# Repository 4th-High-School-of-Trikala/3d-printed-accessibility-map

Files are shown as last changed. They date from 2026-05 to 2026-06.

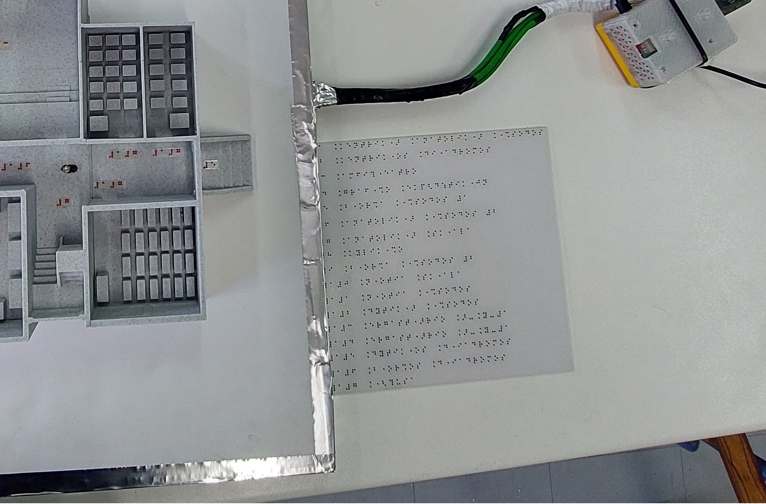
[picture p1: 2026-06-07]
3dSchoolFloorPlan/photos/floor-plan-21.jpg

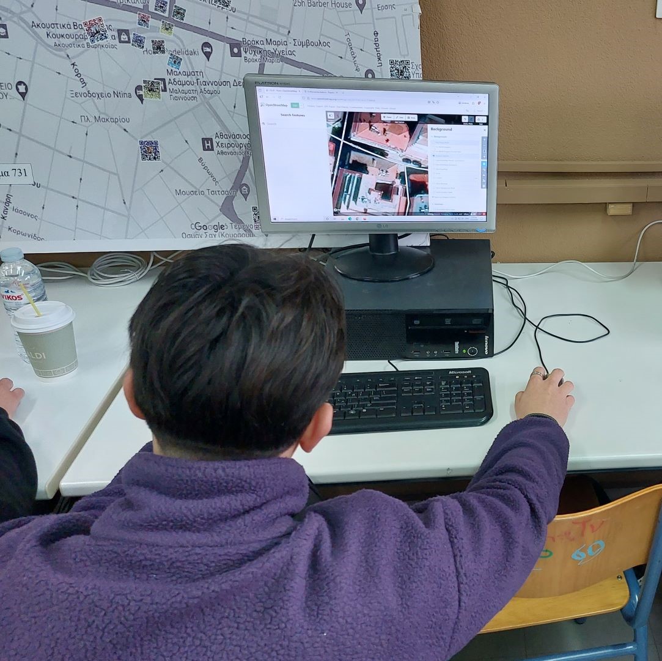
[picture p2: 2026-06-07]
3DMapTrikala/photos/map-3.jpg

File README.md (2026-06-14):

# Διαδραστικός 3D Εκτυπωμένος Χάρτης Προσβασιμότητας
Οι μαθητές, οι μαθήτριες και οι εκπαιδευτικοί των Ομίλων «STEM, 3D & AI» και «TechArt: Τεχνολογία, Δημιουργία, Καινοτομία» του 4ου Πειραματικού ΓΕΛ Τρικάλων, κατασκεύασαν ένα καινοτόμο εκπαιδευτικό έργο **σε πραγματική κλίμακα**, που αξιοποιεί την τεχνολογία, για την ενίσχυση της προσβασιμότητας στην πολιτιστική κληρονομιά της πόλης των Τρικάλων.  
Πιο συγκεκριμένα, σχεδιάσαν και εκτύπωσαν με τεχνολογία FDM 3D εκτύπωσης δύο ανάγλυφους χάρτες (χάρτες αφής):
- Ο πρώτος χάρτης αφορά την πόλη των Τρικάλων και αναπαριστά δρόμους, ποτάμια, κτήρια και πεζοδρόμια, με σκοπό να διευκολυνθεί η πλοήγηση ατόμων με προβλήματα όρασης στα κυριότερα ιστορικά σημεία και αξιοθέατα. Σε κάθε σημείο ενδιαφέροντος (μνημεία, αγάλματα, αξιοθέατα) της πόλης, τοποθετήθηκαν διαδραστικά κουμπιά, (push buttons ή αφής), τα οποία συνδέθηκαν με μικροϋπολογιστή Raspberry Pi και προγραμματίστηκαν κατάλληλα ώστε με το πάτημα κάθε κουμπιού να προβάλλεται σε οθόνη, βίντεο με ιστορικές πληροφορίες (και κατάλληλο QR Code) και να **ακούγεται** η αντίστοιχη περιγραφή του σημείου. Τα βίντεο έχουν ήδη δημιουργηθεί από συμμαθητές/τριες τους, στο πλαίσιο πολιτιστικού προγράμματος.
- Ο δεύτερος χάρτης (τρισδιάστατη κάτοψη) αφορά το σχολείο μας (και τους 2 ορόφους) και δημιουργήθηκε ως παράδειγμα υλοποίησης 3D αναπαράστασης ενός σημείου ενδιαφέροντος. Η δεύτερη αναπαράσταση βοηθά στην περιήγηση στο σημείο ενδιαφέροντος και μπορεί να δημιουργηθεί για κάθε ένα από τα μνημεία/αξιοθέατα/αγάλματα κτλ.

Με τον τρόπο αυτό όλοι οι επισκέπτες και οι κάτοικοι της πόλης μας αποκτούν ισότιμη πρόσβαση στην πολιτιστική της κληρονομιά.

## Ενδεικτική λίστα υλικών

- Ένα (ή δύο ανάλογα με την υλοποίηση) Raspberry Pi (με κάρτα μνήμης τουλάχιστον 16 GB) και παρελκόμενα
- 8 Stomp Switches (non-latching) ή push buttons.
- 5 αισθητήρες απόστασης/αποφυγής εμποδίων (υπερύθρων - TCRT5000)
- 16 αντιστάσεις, 8 πυκνωτές, μία διάτρητη πλακέτα και 10 κλέμες
- Καλωδίωση, μη ευαίσθητη στις παρεμβολές, κατάλληλη για την σύνδεση των κουμπιών με το Raspberry Pi.
- Κατάλληλο πλαίσιο και βάση (μακετόχαρτο) για την στήριξη των χαρτών (100x70 εκατοστά)
- Filament για την εκτύπωση του χάρτη και των κατόψεων (περίπου 3 κιλά).
- C-Media USB Headphone Set (USB κάρτα ήχου)

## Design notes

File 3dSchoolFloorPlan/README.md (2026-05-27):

Το πρόγραμμα πίσω απο το «Διαδραστικό 3D Εκτυπωμένο Σημείο Ενδιαφέροντος», των Ομίλων «STEM, 3D & AI» και «TechArt: Τεχνολογία, Δημιουργία, Καινοτομία» του 4ου Πειραματικού ΓΕΛ Τρικάλων. Γραμμένο σε Python, απο τους μαθητές του Ομίλου, για να τρέχει στα Raspberry Pi.

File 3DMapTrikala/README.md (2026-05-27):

# 4peirlyk PyVLC Player
Το πρόγραμμα πίσω απο τον «Διαδραστικό 3D Εκτυπωμένο Χάρτη Προσβασιμότητας», των Ομίλων «STEM, 3D & AI» και «TechArt: Τεχνολογία, Δημιουργία, Καινοτομία» του 4ου Πειραματικού ΓΕΛ Τρικάλων.
Γραμμένο σε Python, απο τους μαθητές του Ομίλου, για να τρέχει στα Raspberry Pi.

## Οργάνωση του Project

```bash
.
├── config.toml: Ρυθμίσεις Προγράμματος
└── src
    ├── gpio.py: Διαχείριση GPIO 
    ├── gui 
    │   ├── alert.py: Παράθυρο Ειδοποίησης
    │   └── vlc.py: VLC Player
    ├── main.py: Σημείο εισόδου
    ├── qr.py: Δημιουργία QR Code
    └── uri.py: Έλεγχος URI 
```

## Demo

```mermaid
sequenceDiagram
  participant Οθόνη
  participant Πρόγραμμα
  participant RPI
  actor Χρήστης

  Note over RPI: Η δοκιμασμένη πλατφόρμα ήταν ένα Raspberry Pi 4.<br/>Λογικά λειτουργεί με όλες τις κύριες πλακέτες RPI.
  Note over Πρόγραμμα,RPI: Διαδικασία εκκίνησης
  Πρόγραμμα ->> Πρόγραμμα: Προφόρτωση μέσων και έλεγχος εγκυρότητας URI

  Πρόγραμμα ->> RPI: Ρύθμιση GPIO
  Πρόγραμμα ->> Πρόγραμμα: Εγγραφή αναπαραγώγιμων πολυμέσεων και Callback

  Πρόγραμμα ->> Οθόνη: Εγγραφή πολυμέσων και εγγραφή Callback
  Πρόγραμμα ->> Οθόνη: Αναπαραγωγή IDLE

  Note over Πρόγραμμα,RPI: Διαδικασία μετά το πάτημα του κουμπιού
  Χρήστης ->> RPI: Πάτημα κουμπιού
  RPI -->> Πρόγραμμα: Κλήση Callback
  Πρόγραμμα ->> Πρόγραμμα: Φορτώνει το κατάλληλο πολυμέσο από Ρυθμίσεις
  Πρόγραμμα ->> Πρόγραμμα: Δημιουργία QR κωδικού
  Πρόγραμμα ->> Οθόνη: Ορισμός πολυμέσων από λίστα
  Πρόγραμμα ->> Οθόνη: Επικάλυψη QR Code

  Note over Πρόγραμμα,RPI: Όταν ολοκληρωθεί η <br/> αναπαραγωγή πολυμέσων
  Πρόγραμμα ->> Οθόνη: Αναπαραγωγή IDLE
  Πρόγραμμα ->> Οθόνη: Απόκρυψη κωδικού QR
```

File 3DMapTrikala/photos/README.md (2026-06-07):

Φωτογραφίες από την διαδικασία σχεδίασης και κατασκευής

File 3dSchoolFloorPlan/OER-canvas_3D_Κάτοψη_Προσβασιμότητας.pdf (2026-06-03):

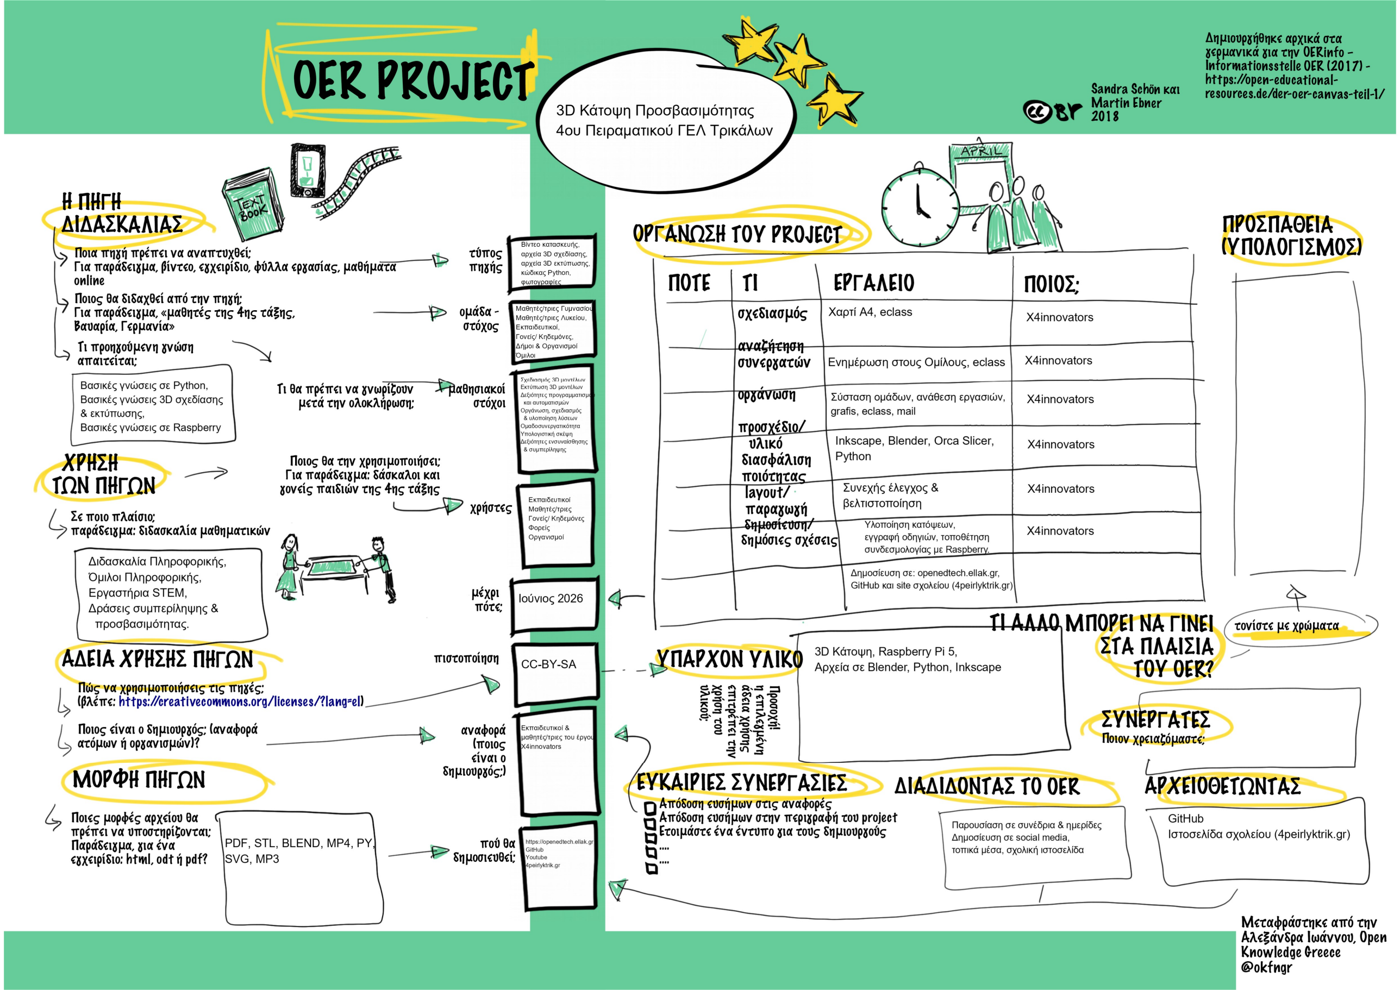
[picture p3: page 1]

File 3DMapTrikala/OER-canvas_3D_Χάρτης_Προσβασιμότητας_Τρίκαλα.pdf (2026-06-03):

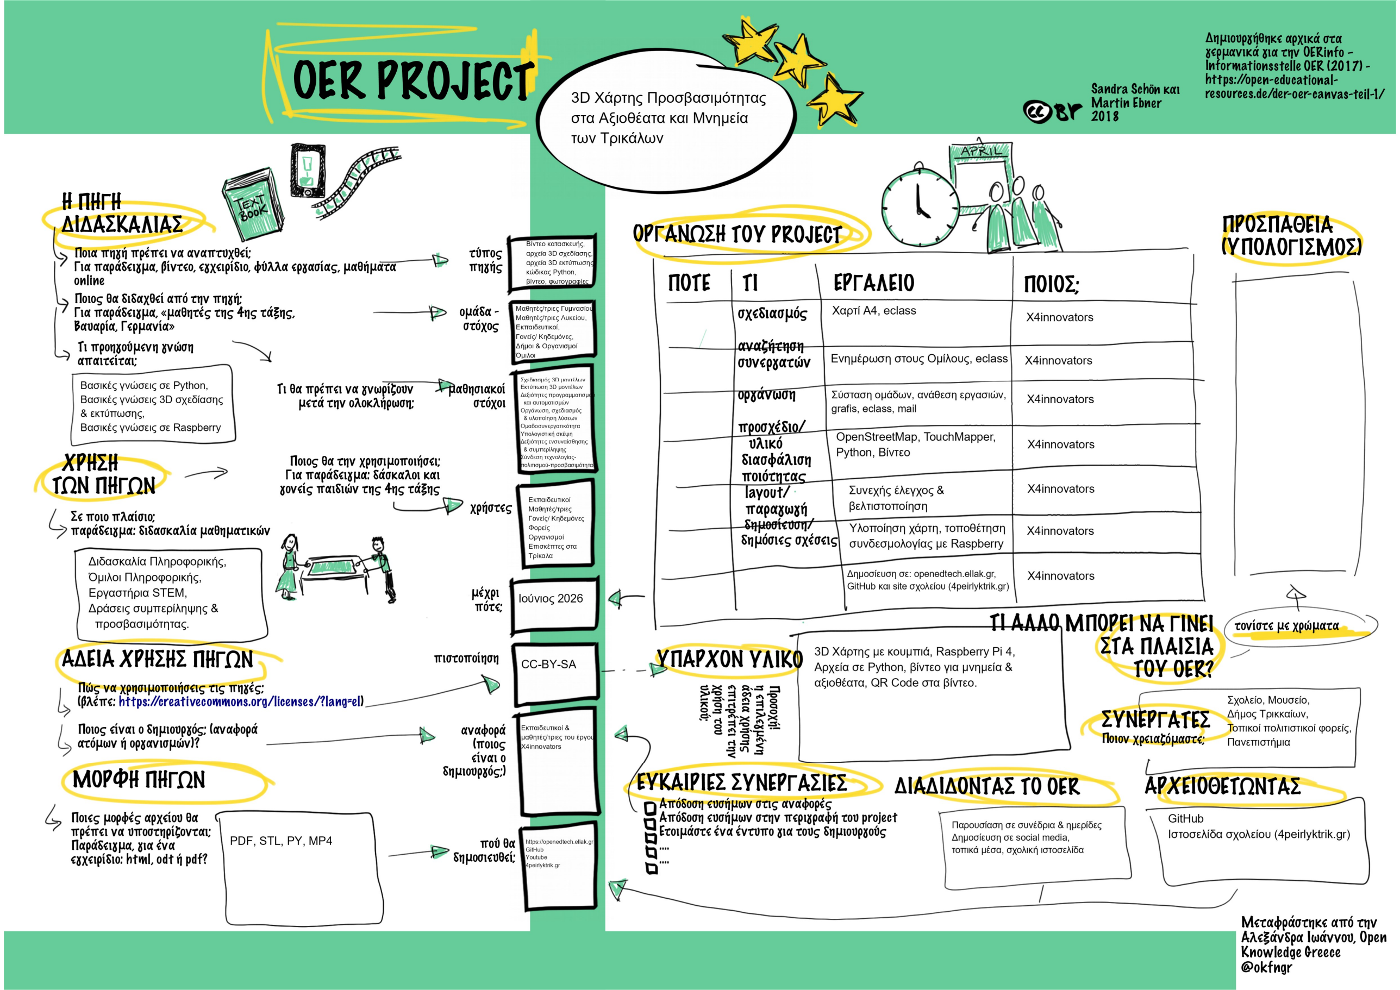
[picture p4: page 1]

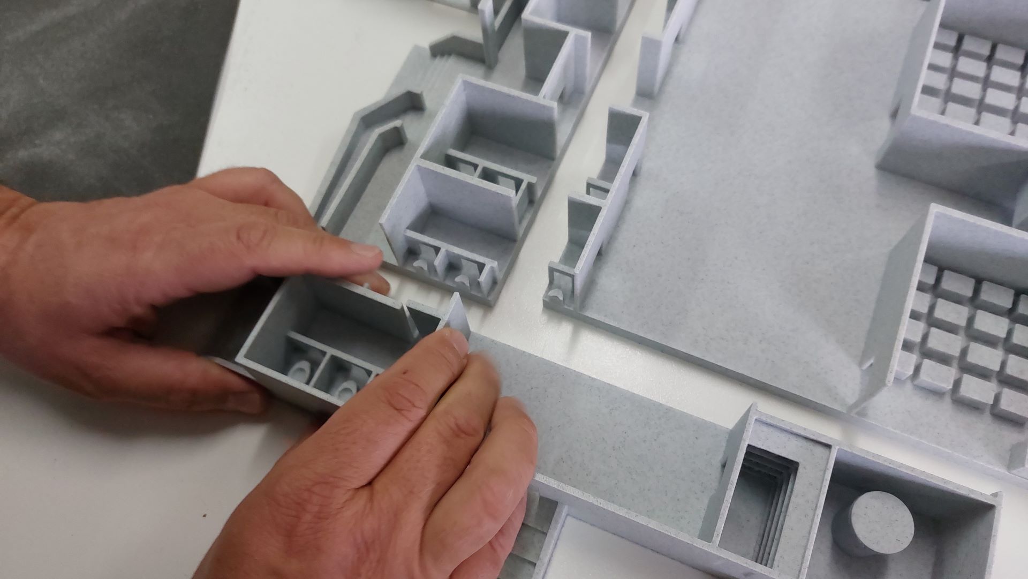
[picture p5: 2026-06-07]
3dSchoolFloorPlan/photos/floor-plan-10.jpg

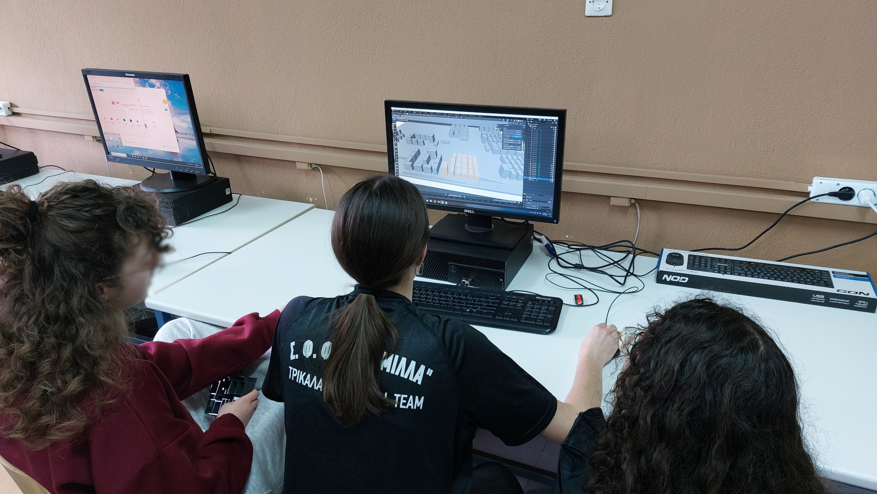
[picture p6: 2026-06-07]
3dSchoolFloorPlan/photos/floor-plan-4.jpg

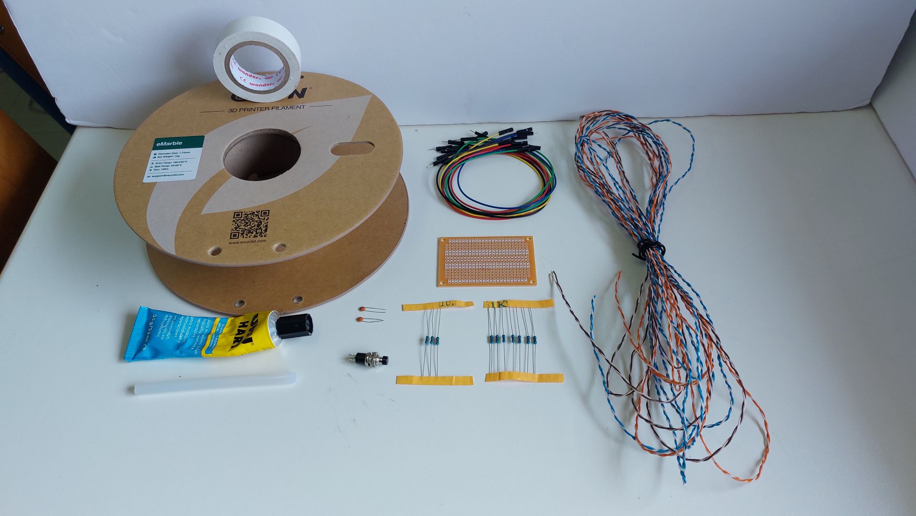
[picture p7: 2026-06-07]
3DMapTrikala/photos/ylika_xarti.jpg

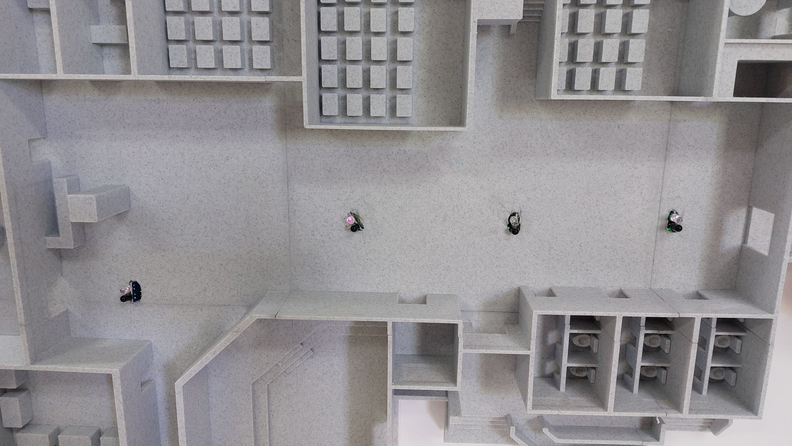
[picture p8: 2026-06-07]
3dSchoolFloorPlan/photos/floor-plan-15.jpg

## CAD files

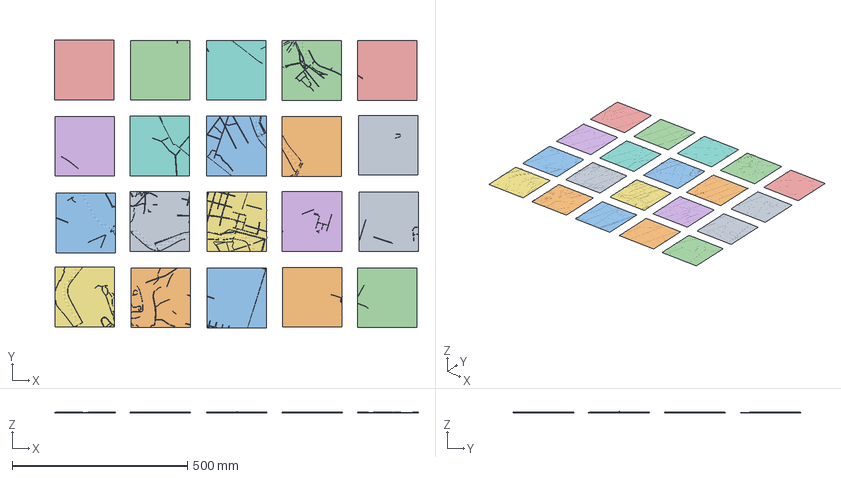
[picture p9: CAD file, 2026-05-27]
3DMapTrikala/assets/3mf/TrikalaALL-orca.3mf
1037.5 x 821.2 x 5.49 mm
Trikala-m100X-p0Y.stl
Trikala-m100X-p100Y.stl
Trikala-m200X-p0Y.stl
Trikala-p100X-m200Y.stl
Trikala-p200X-m200Y.stl
Trikala-p100X-p0Y.stl
Trikala-m200X-p100Y.stl
Trikala-p0X-m200Y.stl
Trikala-p200X-p0Y.stl
Trikala-p100X-m100Y.stl
Trikala-p0X-m100Y.stl
Trikala-m100X-m200Y.stl
Trikala-m200X-m200Y.stl
Trikala-m200X-m100Y.stl
Trikala-p0X-p0Y.stl
Trikala-m100X-m100Y.stl
Trikala-p200X-m100Y.stl
Trikala-p100X-p100Y.stl
Trikala-p0X-p100Y.stl
Trikala-p200X-p100Y.stl

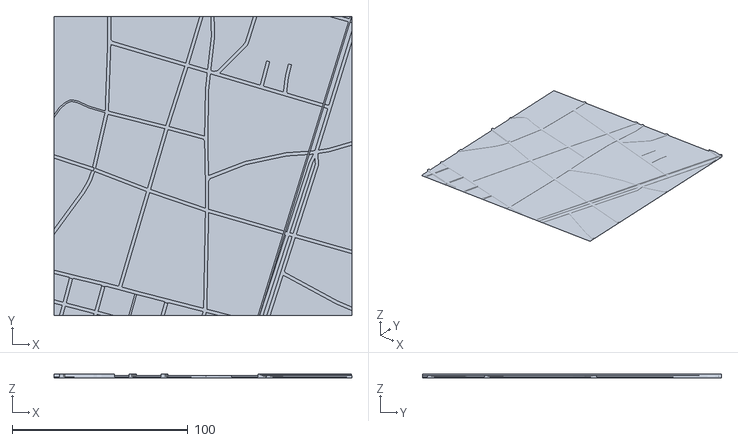
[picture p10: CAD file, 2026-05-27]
3DMapTrikala/assets/stl/Trikala-p0X-p100Y.stl
169.8 x 170.5 x 2.11

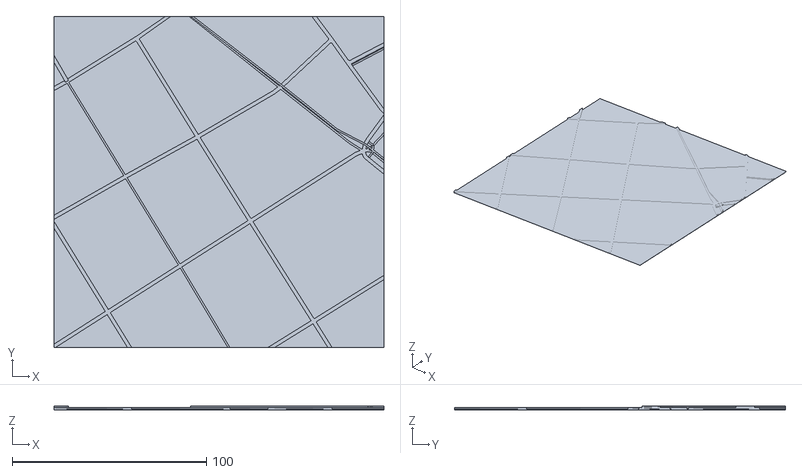
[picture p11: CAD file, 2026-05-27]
3DMapTrikala/assets/stl/Trikala-p0X-m200Y.stl
169.8 x 170.5 x 2.11

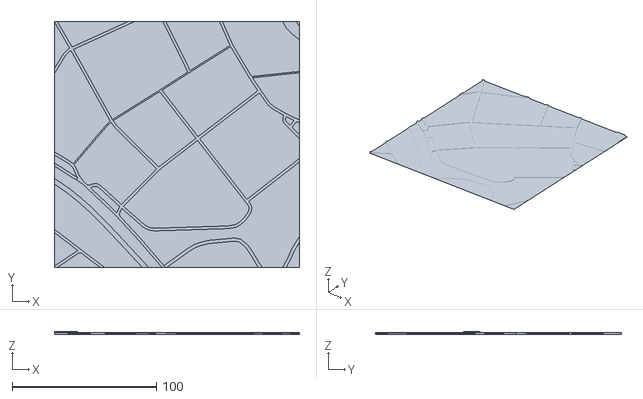
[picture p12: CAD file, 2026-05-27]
3DMapTrikala/assets/stl/Trikala-p200X-m200Y.stl
169.8 x 170.5 x 2.11

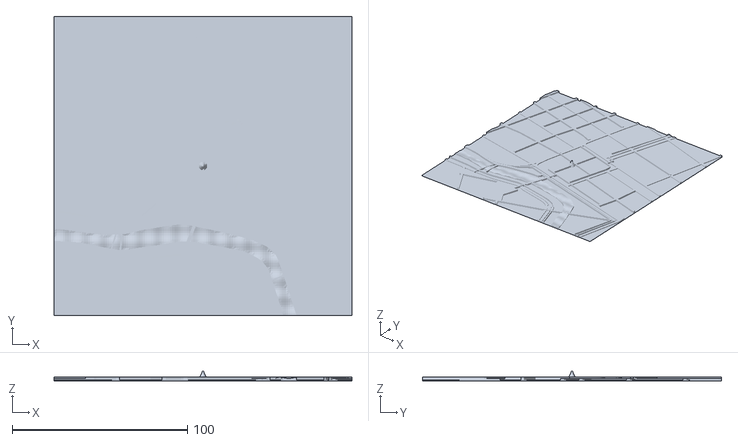
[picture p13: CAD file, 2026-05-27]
3DMapTrikala/assets/stl/Trikala-p0X-p0Y.stl
169.8 x 170.5 x 5.49

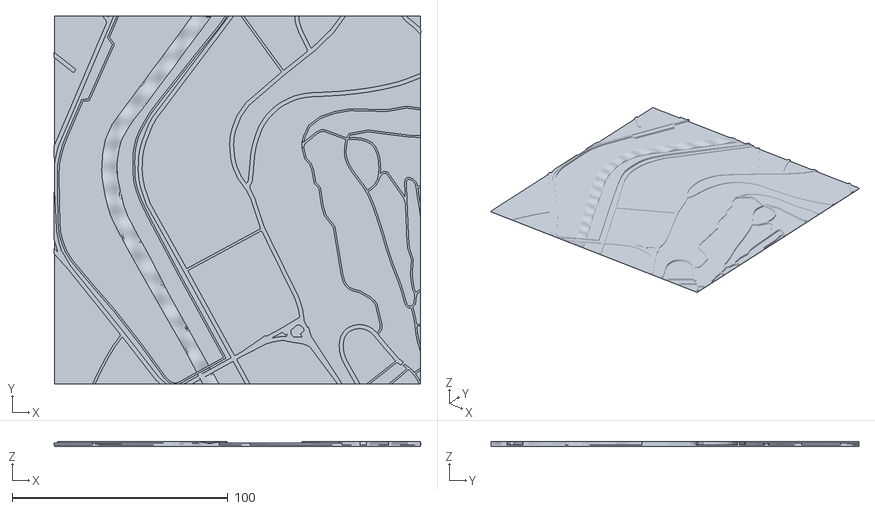
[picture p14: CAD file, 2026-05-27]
3DMapTrikala/assets/stl/Trikala-m200X-p100Y.stl
169.8 x 170.5 x 2.12

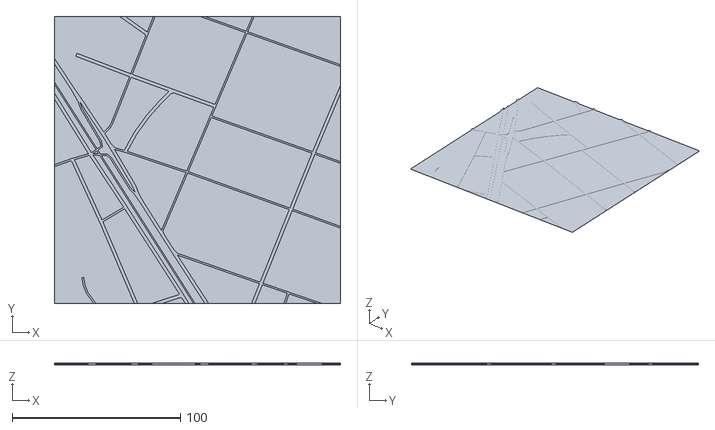
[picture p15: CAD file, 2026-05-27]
3DMapTrikala/assets/stl/Trikala-m200X-m200Y.stl
169.8 x 170.5 x 1.44

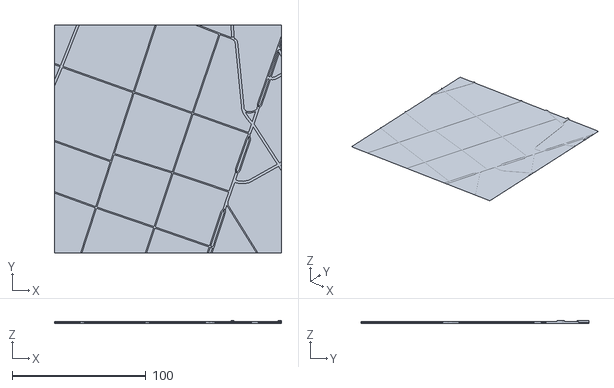
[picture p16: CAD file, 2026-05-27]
3DMapTrikala/assets/stl/Trikala-m100X-m200Y.stl
169.8 x 170.5 x 2.11

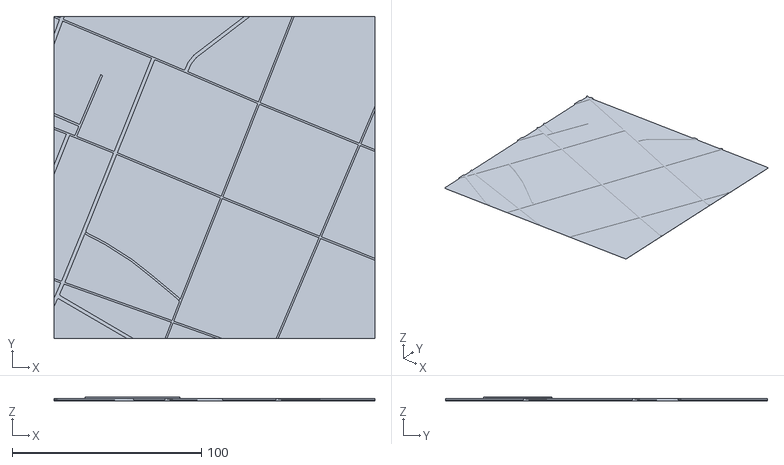
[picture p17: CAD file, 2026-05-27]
3DMapTrikala/assets/stl/Trikala-m200X-m100Y.stl
169.8 x 170.5 x 2.11

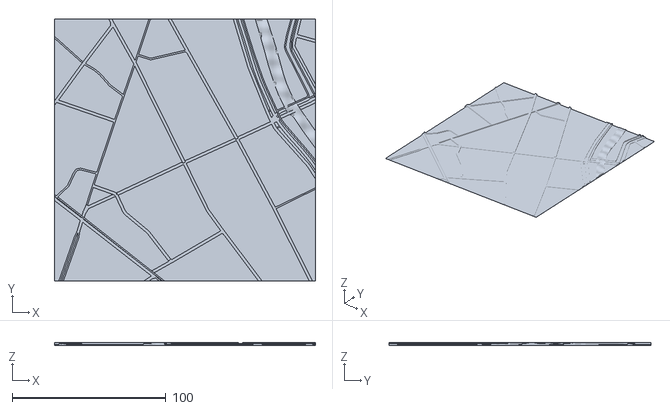
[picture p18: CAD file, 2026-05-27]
3DMapTrikala/assets/stl/Trikala-p0X-m100Y.stl
169.8 x 170.5 x 2.11

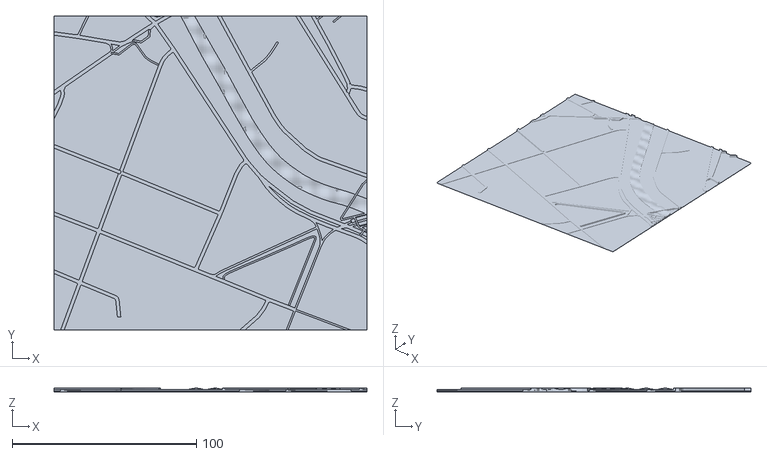
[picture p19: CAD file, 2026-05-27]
3DMapTrikala/assets/stl/Trikala-m200X-p0Y.stl
169.9 x 170.5 x 2.11

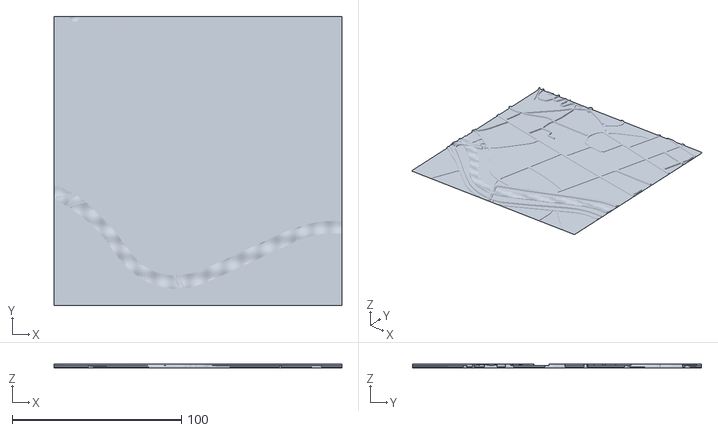
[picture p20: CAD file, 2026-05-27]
3DMapTrikala/assets/stl/Trikala-m100X-p0Y.stl
169.9 x 170.5 x 2.12

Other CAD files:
3DMapTrikala/assets/stl/Trikala-p100X-p0Y.stl
3DMapTrikala/assets/stl/Trikala-p100X-p100Y.stl
3DMapTrikala/assets/stl/Trikala-m100X-p100Y.stl
3DMapTrikala/assets/stl/Trikala-p200X-p0Y.stl
3DMapTrikala/assets/stl/Trikala-p200X-p100Y.stl
3DMapTrikala/assets/stl/Trikala-p100X-m100Y.stl
3DMapTrikala/assets/stl/Trikala-m100X-m100Y.stl
3DMapTrikala/assets/stl/Trikala-p100X-m200Y.stl
3DMapTrikala/assets/stl/Trikala-p200X-m100Y.stl
3dSchoolFloorPlan/kato_orofos - TELIKO.blend
3dSchoolFloorPlan/pano_orofos - TELIKO.blend

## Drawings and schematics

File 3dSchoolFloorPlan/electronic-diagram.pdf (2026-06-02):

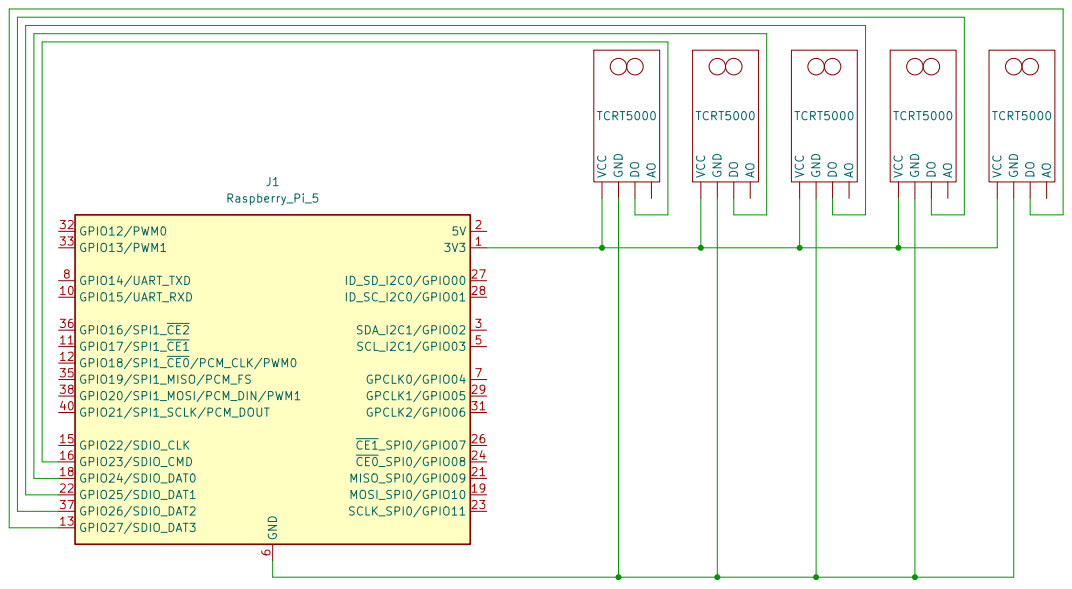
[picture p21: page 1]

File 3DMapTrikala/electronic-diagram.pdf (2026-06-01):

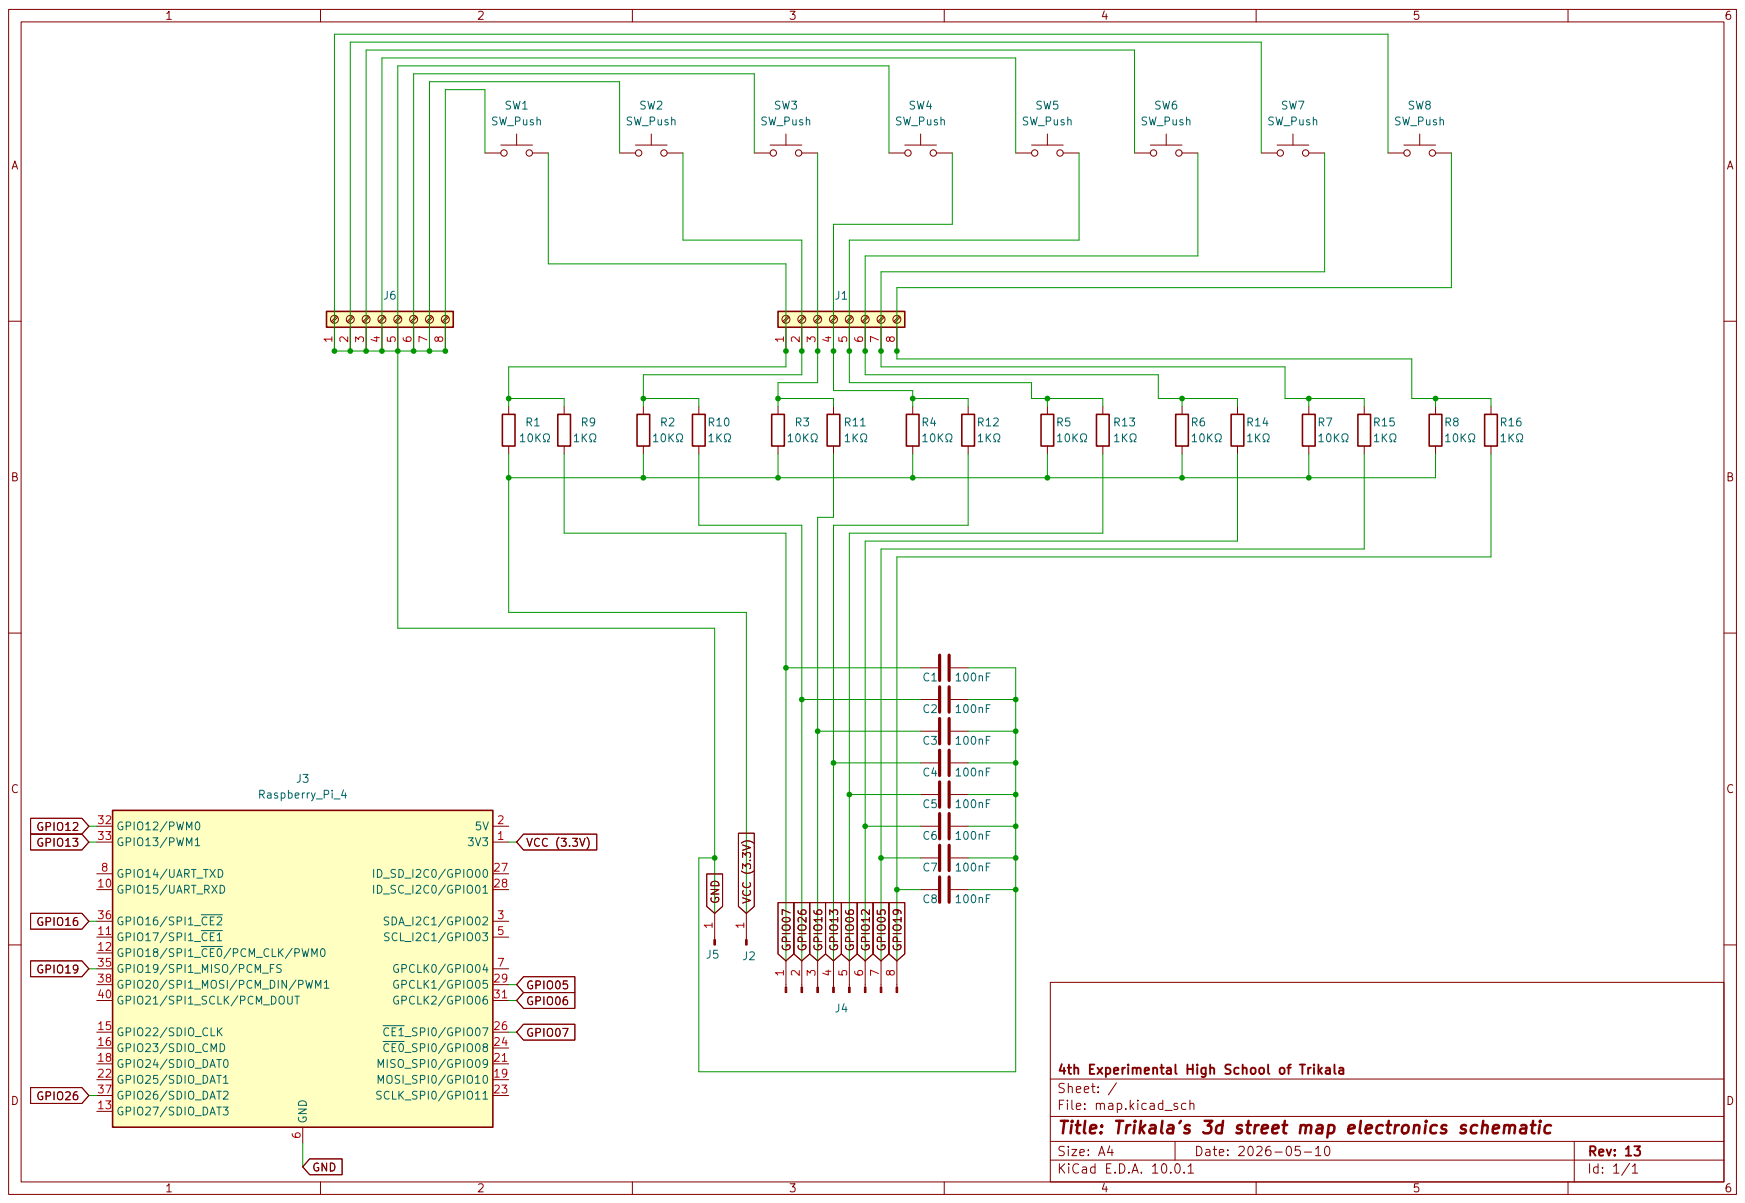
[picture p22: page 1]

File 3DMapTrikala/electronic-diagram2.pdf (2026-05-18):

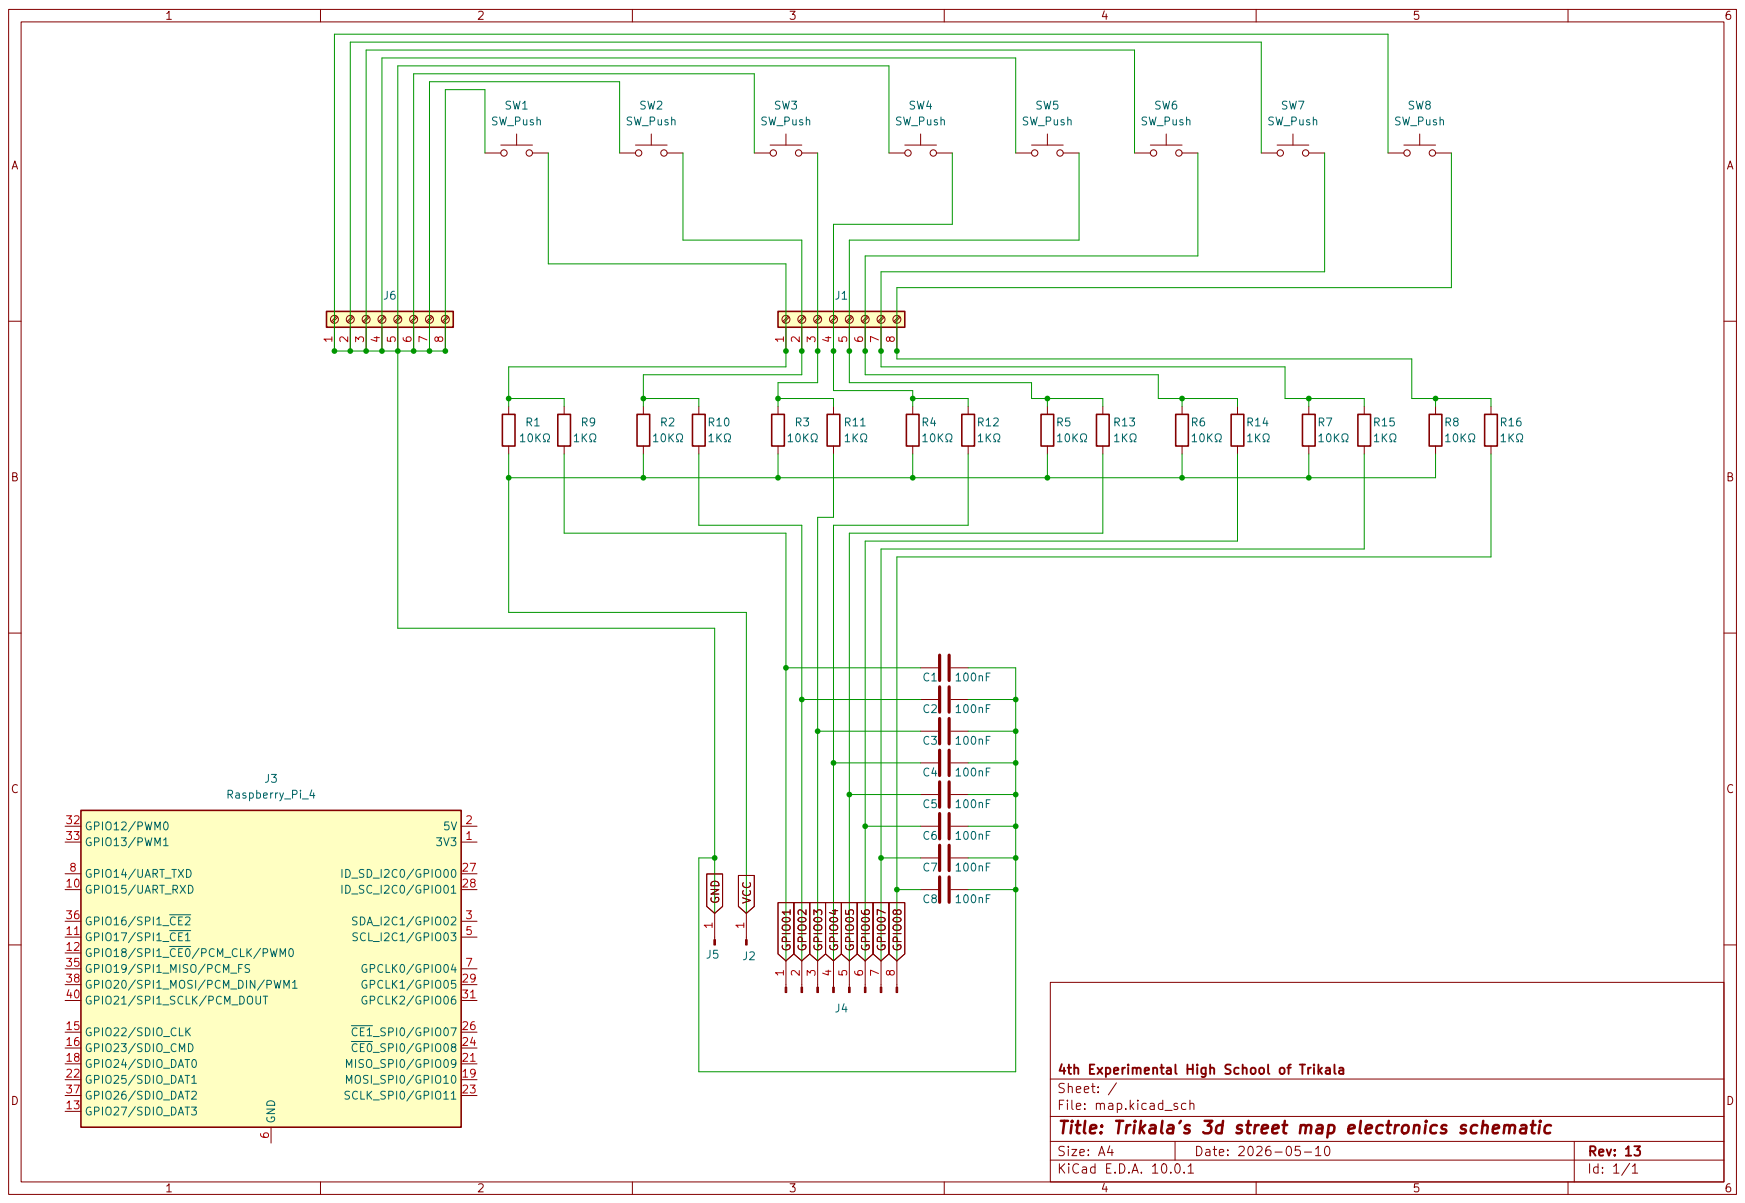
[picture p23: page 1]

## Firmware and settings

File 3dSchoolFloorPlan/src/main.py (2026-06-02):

import pygame
from gpiozero import Button
from signal import pause
import time

pygame.mixer.init(devicename="C-Media USB Headphone Set, USB Audio")
sound=pygame.mixer.Sound("sound2.mp3")
pl = 0

def in23():
    global pl
    global sound
    if pl != 1:
        pl = 1
        sound.stop()
        sound=pygame.mixer.Sound("nar_central1.mp3")
        sound.play(0)
        time.sleep(5)
        pl = 0
    return

def in24() :
    global sound
    global pl
    if pl != 2:
        pl = 2
        sound.stop()
        sound=pygame.mixer.Sound("nar_Eex.mp3")
        sound.play(0)
        time.sleep(5)
        pl = 0
    return

def in25():
    global pl
    global sound
    if pl != 3:
        pl = 3
        sound.stop()
        sound=pygame.mixer.Sound("nar_Wex.mp3")
        sound.play(0)
        time.sleep(5)
        pl = 0
    return

def in26():
    global pl
    global sound
    if pl != 4:
        pl = 4
        sound.stop()
        sound=pygame.mixer.Sound("nar_central2.mp3")
        sound.play(0)
        time.sleep(5)
        pl = 0
    return

def in27():
    global pl
    global sound
    if pl != 5:
        pl = 5
        sound.stop()
        sound=pygame.mixer.Sound("nar_Nex.mp3")
        sound.play(0)
        time.sleep(5)
        pl = 0
    return

button1 = Button(23, pull_up=True, hold_time=0.2)
button2 = Button(24, pull_up=True, hold_time=0.2)
button3 = Button(25, pull_up=True, hold_time=0.2)
button4 = Button(26, pull_up=True, hold_time=0.2)
button5 = Button(27, pull_up=True, hold_time=0.2)


button1.when_held = in23
button2.when_held = in24
button3.when_held = in25
button4.when_held = in26
button5.when_held = in27


pause()

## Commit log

2026-05-14 Ανέβασμα αρχείων .blend του σχολείου
    [kato_orofos - TELIKO.blend, pano_orofos - TELIKO.blend]
2026-05-14 Ανέβασμα αρχείων χάρτη Τρικάλων
2026-05-27 Rename kato_orofos - TELIKO.blend to kato_orofos - TELIKO.blend
    [kato_orofos - TELIKO.blend]
2026-05-27 Rename pano_orofos - TELIKO.blend to pano_orofos - TELIKO.blend
    [pano_orofos - TELIKO.blend]
